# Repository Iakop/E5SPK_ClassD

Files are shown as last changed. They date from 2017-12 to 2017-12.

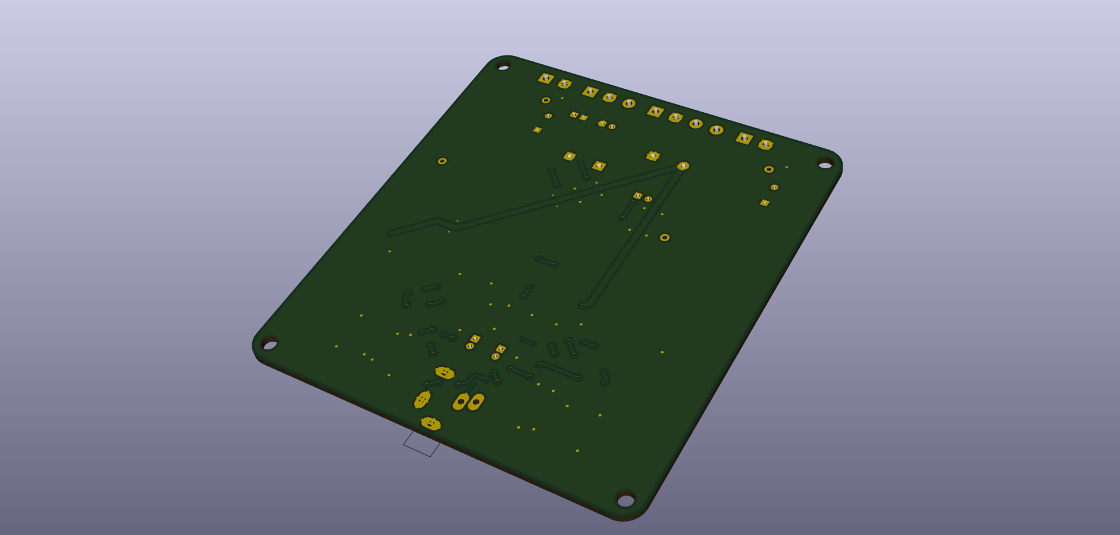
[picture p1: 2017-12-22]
documentation/Class_D_Amp_Bottom.png

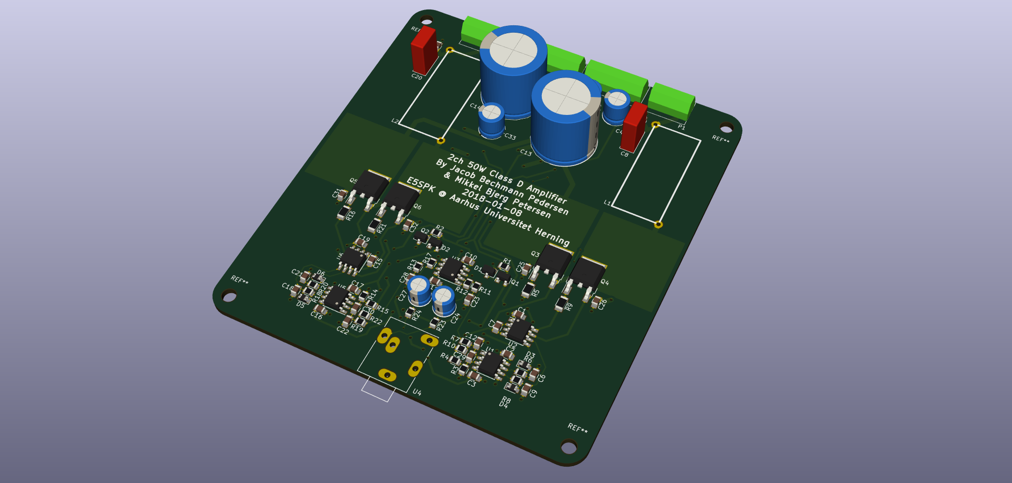
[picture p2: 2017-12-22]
documentation/Class_D_Amp_Top.png

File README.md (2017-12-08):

# E5SPK_ClassD
Class D Amplifier project for the 5th semester course, Switched Power Circuits. By Jacob Bechmann Pedersen and Mikkel Bjerg Petersen.

## Tools 
- The project calculations are alle done in MathCAD Prime
  - but might be converted to another format if needed
- The simulations are done in LTSpice
- Schematics and board layout are done in KiCad

## Key Components
- UCC27201 - 120V bootstrap Half H Driver
- LM360 - 5V High-speed comparator
- IPD180N10N3 - 43A 100V 33mΩ MOSFET DPAK
- BZX84C5V6 - 5.6V Zener Diode
- LM833 - Dual Audio OpAmp
- IES101-4 - TRS Jack connector
- ECA1HM222 - Electorlytic 2200uF Capacitor against supply pumping

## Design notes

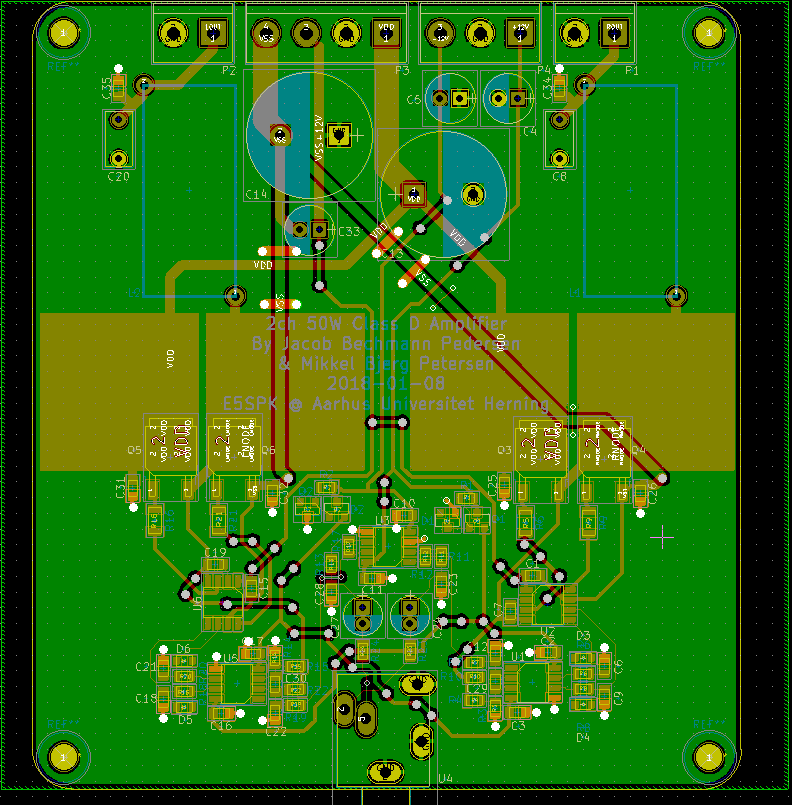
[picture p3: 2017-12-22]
documentation/Board_Layout.png

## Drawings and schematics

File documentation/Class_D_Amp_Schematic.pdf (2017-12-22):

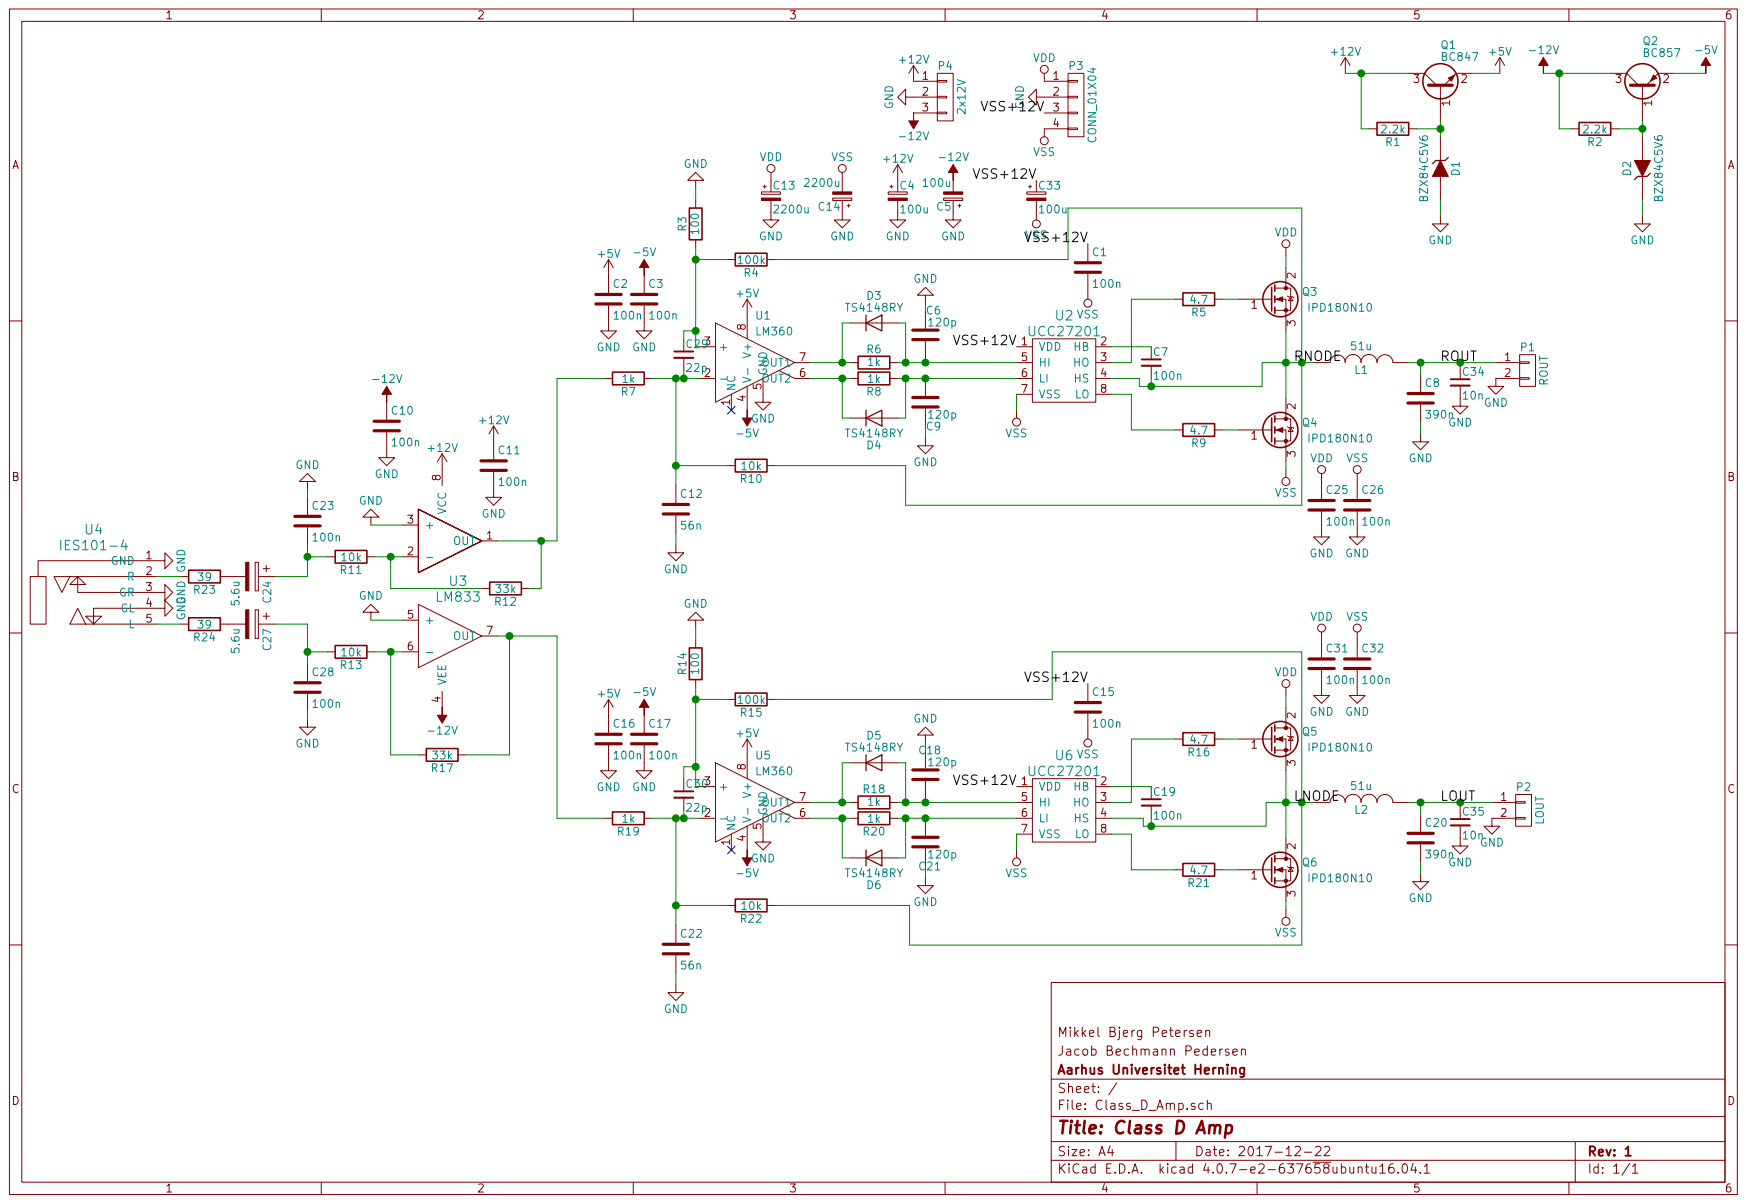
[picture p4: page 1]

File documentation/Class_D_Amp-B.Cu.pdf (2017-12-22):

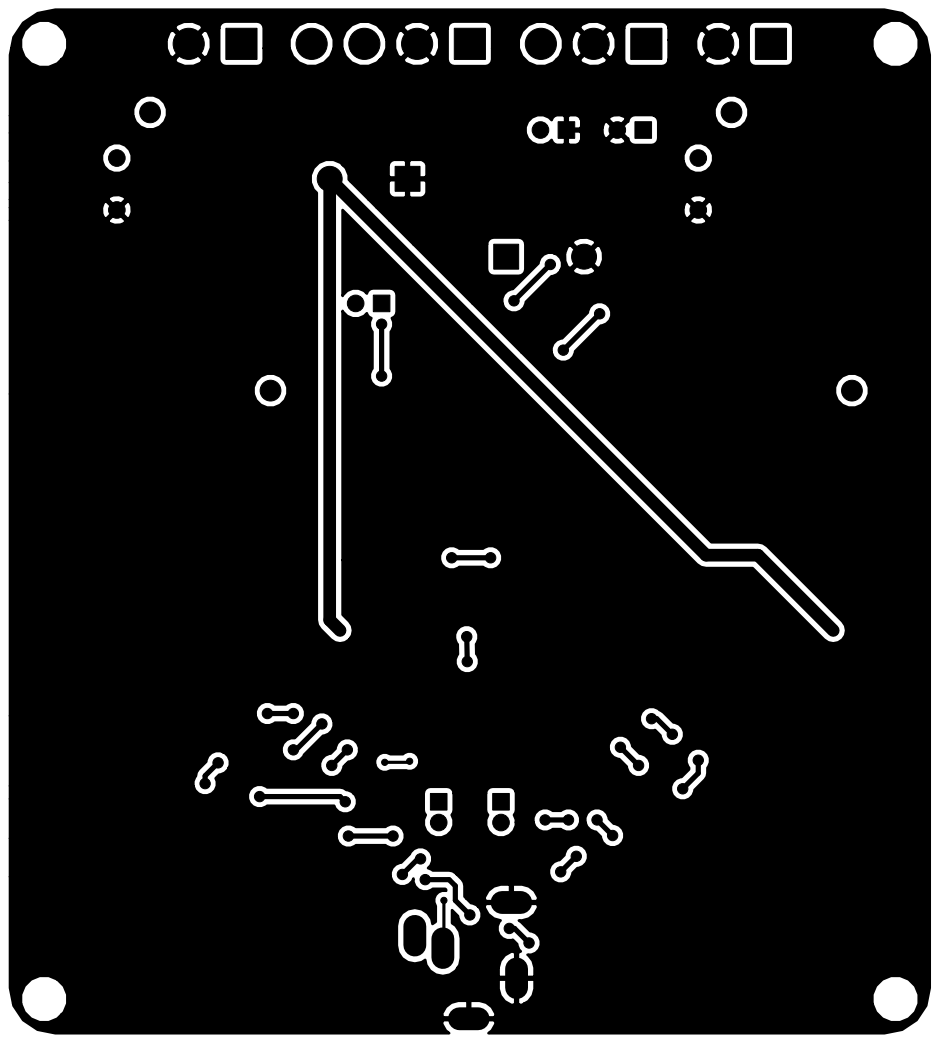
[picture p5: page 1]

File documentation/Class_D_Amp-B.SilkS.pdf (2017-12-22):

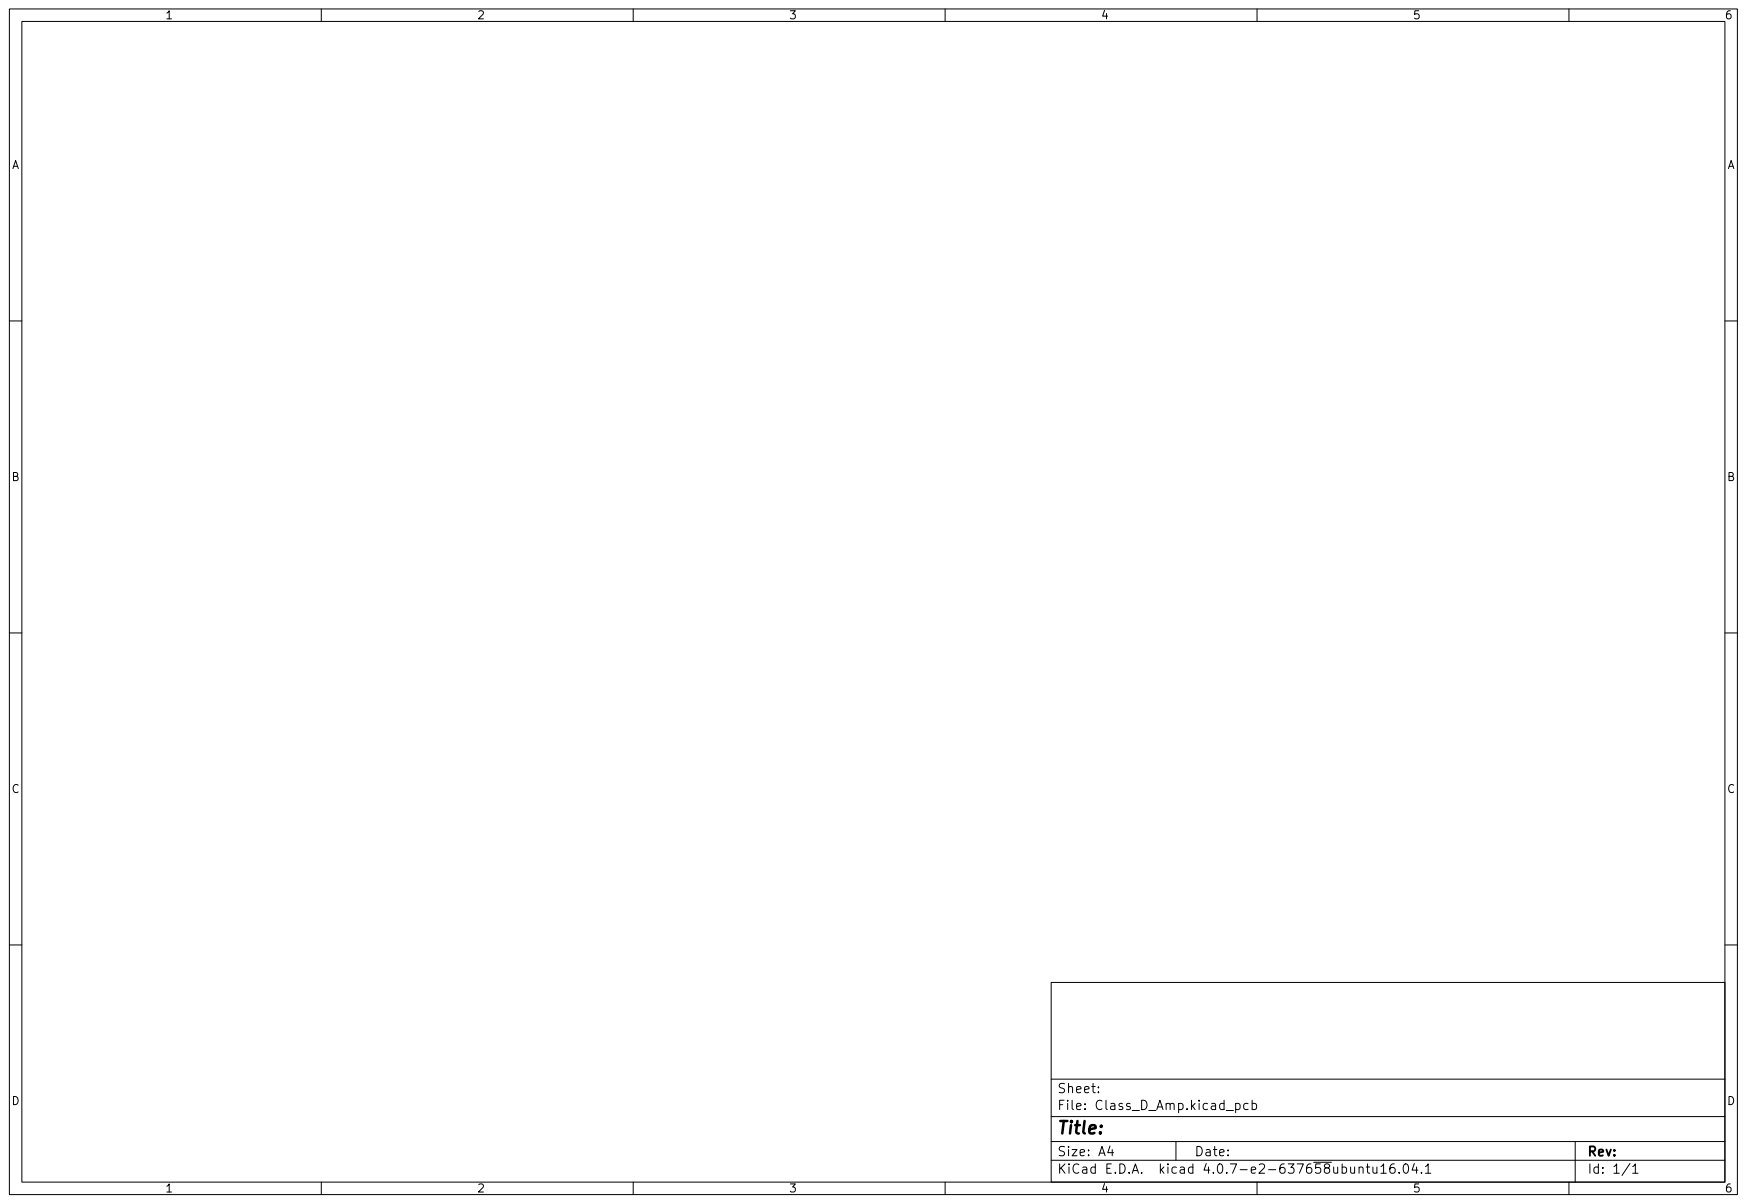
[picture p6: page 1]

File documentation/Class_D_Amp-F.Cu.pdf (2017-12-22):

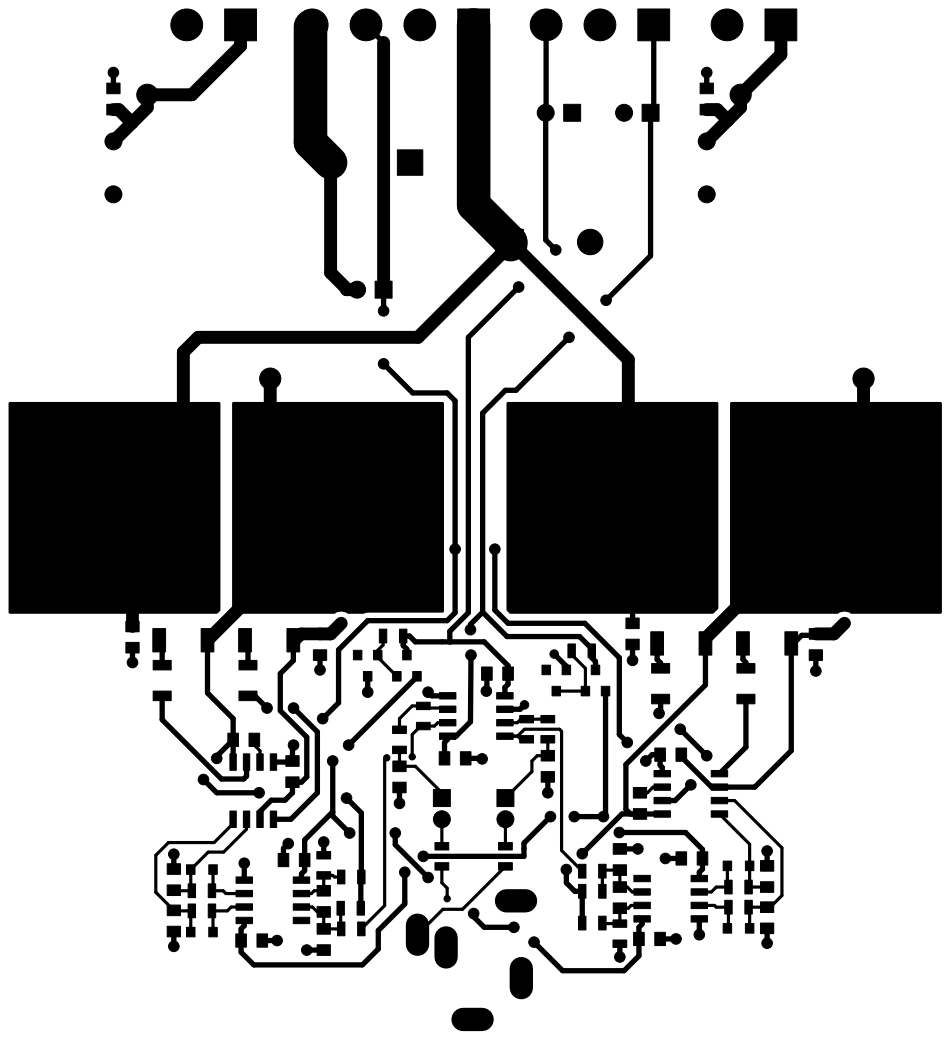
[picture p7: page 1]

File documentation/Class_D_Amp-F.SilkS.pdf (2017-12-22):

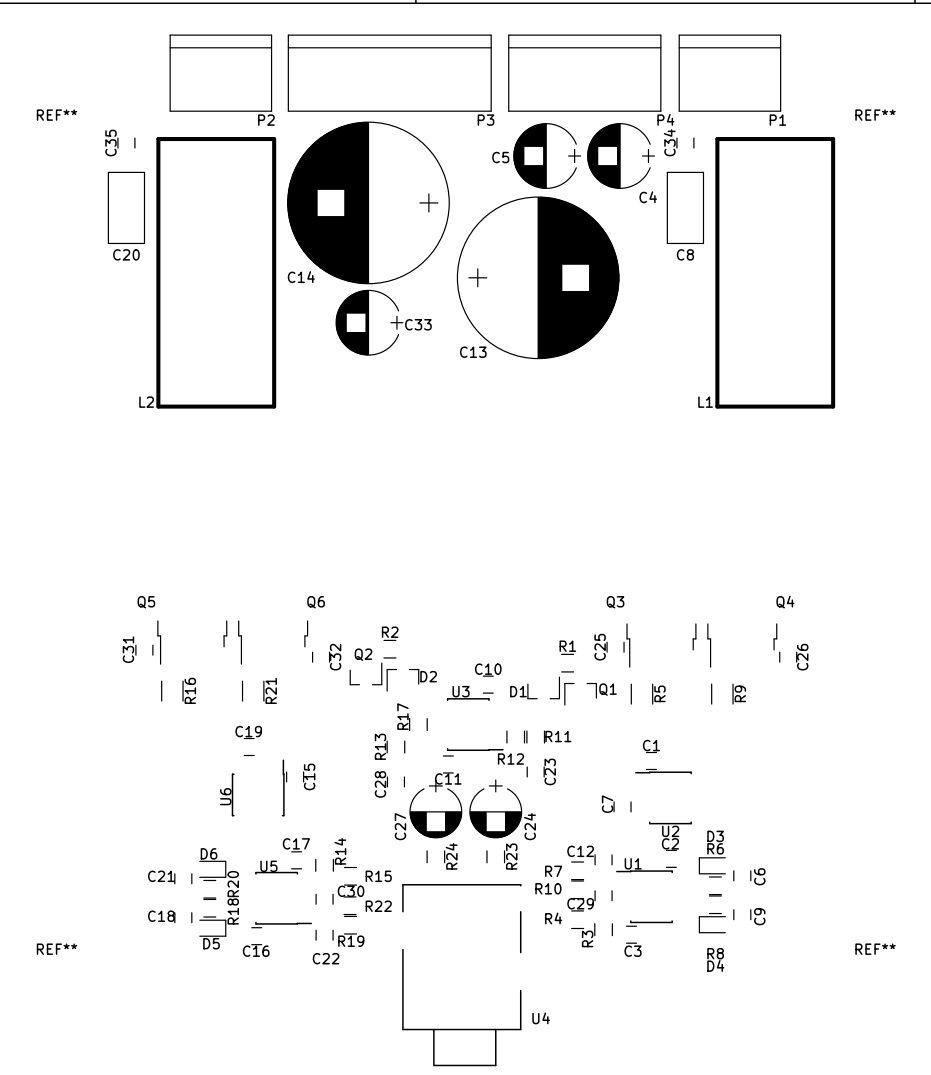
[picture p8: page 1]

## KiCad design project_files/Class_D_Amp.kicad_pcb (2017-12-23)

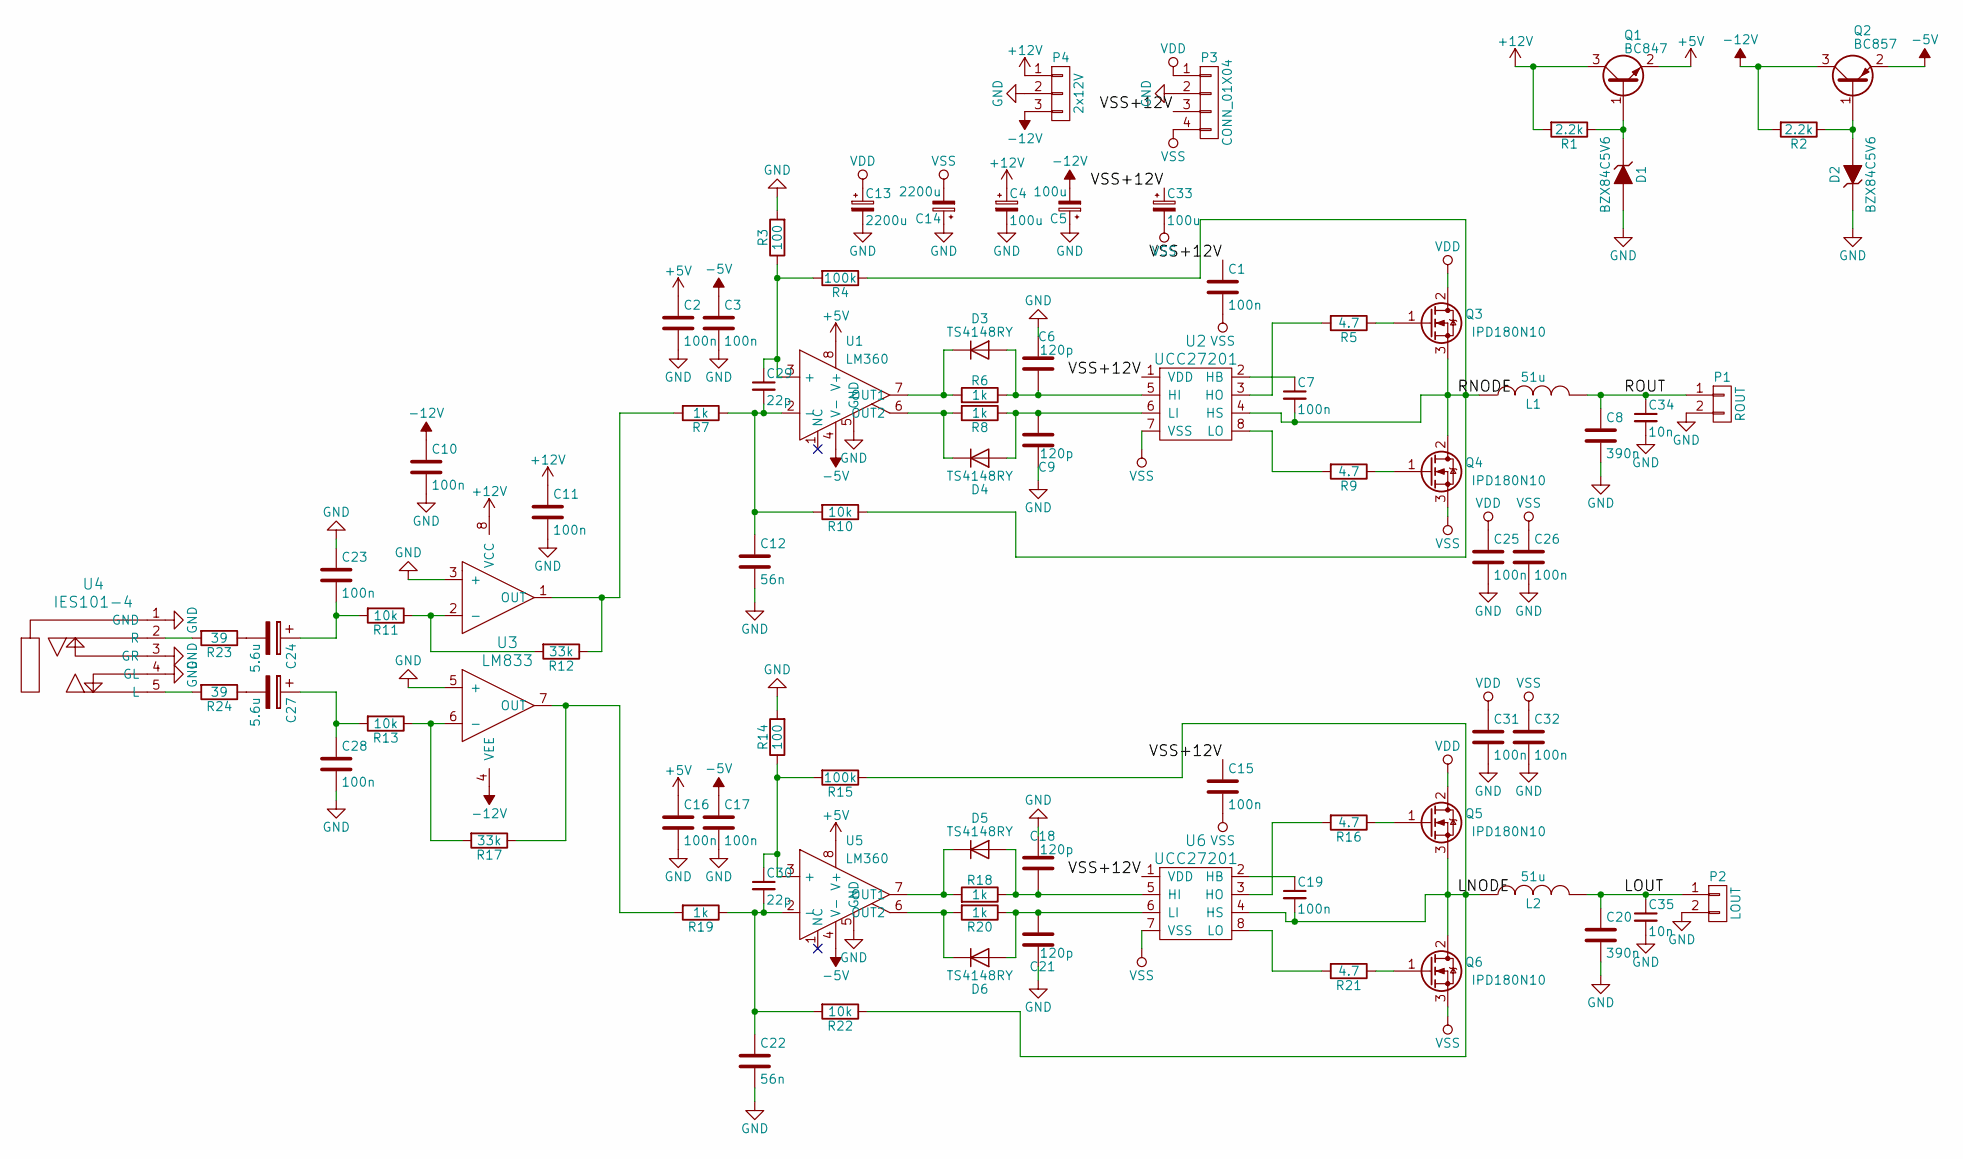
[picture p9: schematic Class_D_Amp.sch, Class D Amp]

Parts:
C1, C2, C3, C7, C10, C11, C15, C16, C17, C19, C23, C25, C26, C28, C31, C32: 100n; C_0805
C4, C5, C33: 100u; CP_Radial_D6.3mm_P2.50mm
C6, C9, C18, C21: 120p; C_0805
C8, C20: 390n; C_Rect_L7.0mm_W3.5mm_P5.00mm
C12, C22: 56n; C_0805
C13, C14: 2200u; CP_Radial_D16.0mm_P7.50mm
C24, C27: 5.6u; CP_Radial_D5.0mm_P2.00mm
C29, C30: 22p; C_0805
C34, C35: 10n; C_0805
D1, D2: BZX84C5V6; SOT-23
D3, D4, D5, D6: TS4148RY; D_0805
L1, L2: 51u; 3C20
P1: ROUT; TerminalBlock_bornier-2_P5.08mm
P2: LOUT; TerminalBlock_bornier-2_P5.08mm
P3: CONN_01X04; TerminalBlock_bornier-4_P5.08mm
P4: 2x12V; TerminalBlock_bornier-3_P5.08mm
Q1: BC847; SOT-23
Q2: BC857; SOT-23
Q3, Q4, Q5, Q6: IPD180N10; TO-252-2
R1, R2: 2.2k; R_0805
R3, R14: 100; R_0805
R4, R15: 100k; R_0805
R5, R9, R16, R21: 4.7; R_1206
R6, R7, R8, R18, R19, R20: 1k; R_0805
R10, R11, R13, R22: 10k; R_0805
R12, R17: 33k; R_0805
R23, R24: 39; R_0805
U1, U5: LM360; SOIC-8_3.9x4.9mm_Pitch1.27mm
U2, U6: UCC27201; SOIC-8_3.9x4.9mm_Pitch1.27mm
U3: LM833; SOIC-8_3.9x4.9mm_Pitch1.27mm
U4: IES101-4; Stereo_Jack_3.5mm_Switch_Ledino_KB3SPRS

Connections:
+5V: C2.1, C16.1, Q1.2 (E), U1.8 (V+), U5.8 (V+)
+12V: C4.1, C11.1, P4.1, Q1.3 (C), R1.2, U3.8 (VCC)
-5V: C3.1, C17.1, Q2.2 (E), U1.4 (V-), U5.4 (V-)
-12V: C5.2, C10.1, P4.3, Q2.3 (C), R2.2, U3.4 (VEE)
/LNODE: C19.2, L2.1, Q5.3 (S), Q6.2 (D), R15.1, R22.1, U6.4 (HS)
/LOUT: C20.1, C35.1, L2.2, P2.1
/RNODE: C7.2, L1.1, Q3.3 (S), Q4.2 (D), R4.1, R10.1, U2.4 (HS)
/ROUT: C8.1, C34.1, L1.2, P1.1
/VSS+12V: C1.1, C15.1, C33.1, P3.3, U2.1 (VDD), U6.1 (VDD)
GND: C2.2, C3.2, C4.2, C5.1, C6.2, C8.2, C9.2, C10.2, C11.2, C12.2, C13.2, C14.1, C16.2, C17.2, C18.2, C20.2, C21.2, C22.2, C23.1, C25.2, C26.2, C28.2, C31.2, C32.2, C34.2, C35.2, D1.1 (A), D2.3 (K), P1.2, P2.2, P3.2, P4.2, R3.2, R14.2, U1.5 (GND), U3.3 (+), U3.5 (+), U4.1 (GND), U4.3 (GR), U4.4 (GL), U5.5 (GND)
unnamed: C6.1, D3.2 (A), R6.1, U2.5 (HI)
unnamed: C7.1, U2.2 (HB)
unnamed: C9.1, D4.2 (A), R8.1, U2.6 (LI)
unnamed: C12.1, C29.2, R7.1, R10.2, U1.2 (-)
unnamed: C18.1, D5.2 (A), R18.1, U6.5 (HI)
unnamed: C19.1, U6.2 (HB)
unnamed: C21.1, D6.2 (A), R20.1, U6.6 (LI)
unnamed: C22.1, C30.2, R19.1, R22.2, U5.2 (-)
unnamed: C23.2, C24.1, R11.2
unnamed: C24.2, R23.1
unnamed: C27.1, C28.1, R13.2
unnamed: C27.2, R24.1
unnamed: C29.1, R3.1, R4.2, U1.3 (+)
unnamed: C30.1, R14.1, R15.2, U5.3 (+)
unnamed: D1.3 (K), Q1.1 (B), R1.1
unnamed: D2.1 (A), Q2.1 (B), R2.1
unnamed: D3.1 (K), R6.2, U1.7 (OUT1)
unnamed: D4.1 (K), R8.2, U1.6 (OUT2)
unnamed: D5.1 (K), R18.2, U5.7 (OUT1)
unnamed: D6.1 (K), R20.2, U5.6 (OUT2)
unnamed: Q3.1 (G), R5.1
unnamed: Q4.1 (G), R9.1
unnamed: Q5.1 (G), R16.1
unnamed: Q6.1 (G), R21.1
unnamed: R5.2, U2.3 (HO)
unnamed: R9.2, U2.8 (LO)
unnamed: R11.1, R12.2, U3.2 (-)
unnamed: R7.2, R12.1, U3.1 (OUT)
unnamed: R13.1, R17.2, U3.6 (-)
unnamed: R16.2, U6.3 (HO)
unnamed: R17.1, R19.2, U3.7 (OUT)
unnamed: R21.2, U6.8 (LO)
unnamed: R23.2, U4.2 (R)
unnamed: R24.2, U4.5 (L)
VDD: C13.1, C25.1, C31.1, P3.1, Q3.2 (D), Q5.2 (D)
VSS: C1.2, C14.2, C15.2, C26.1, C32.1, C33.2, P3.4, Q4.3 (S), Q6.3 (S), U2.7 (VSS), U6.7 (VSS)

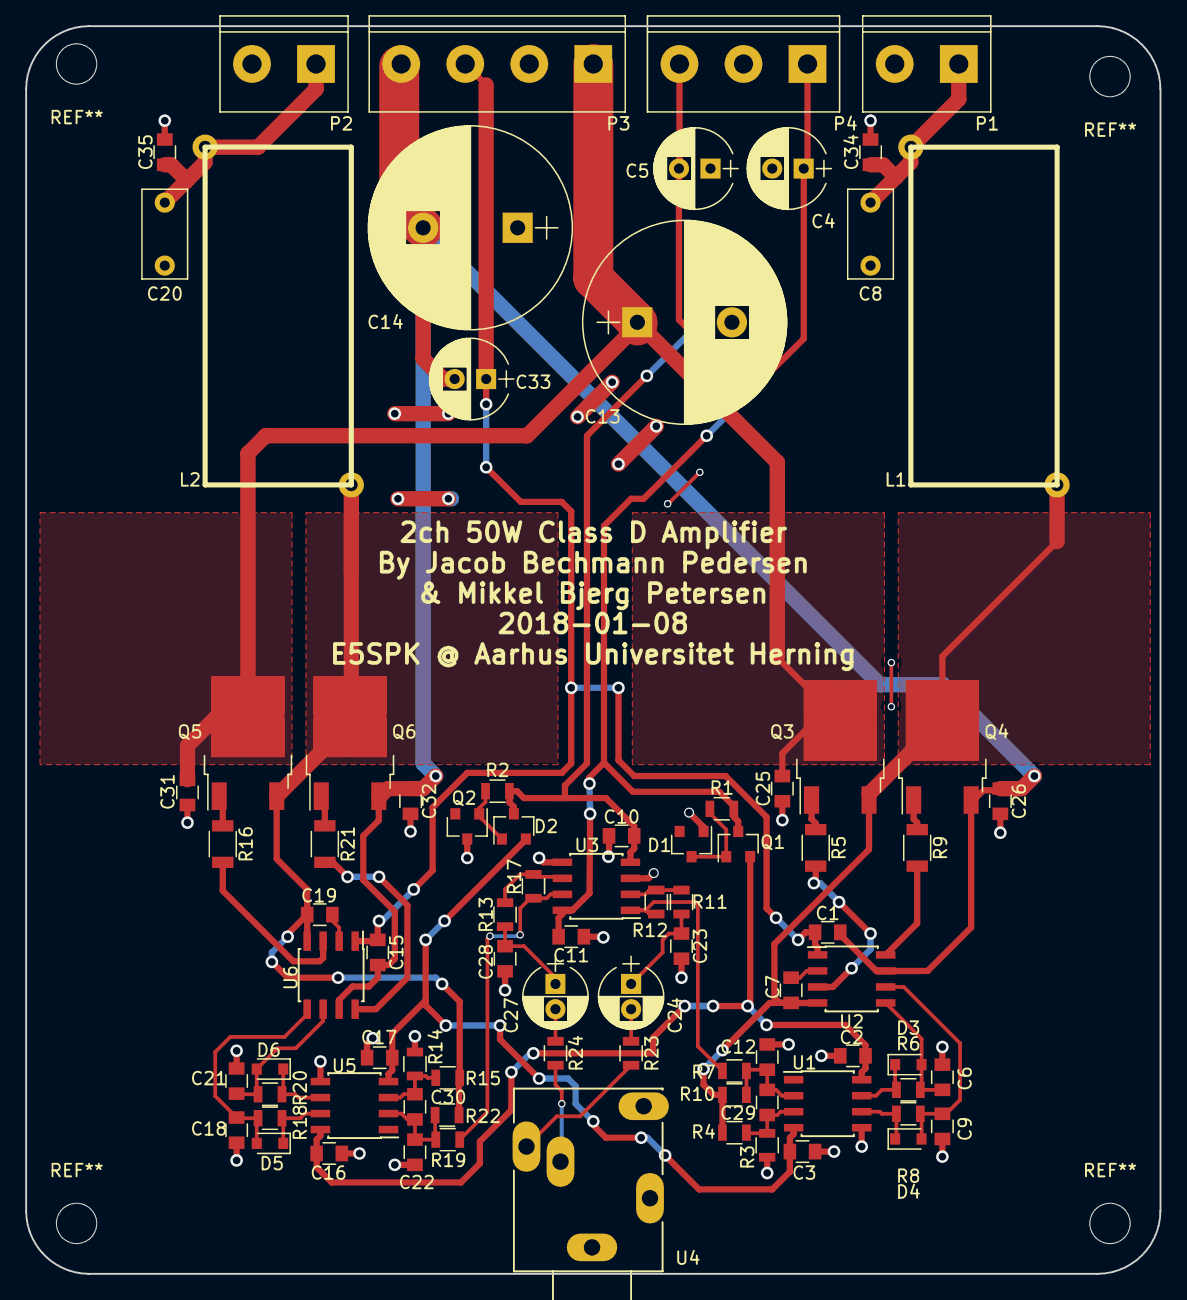
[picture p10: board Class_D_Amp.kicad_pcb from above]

Board: 2 copper layers, 90.0 x 99.0 mm, 83 parts (0 on the bottom side), 46 nets.

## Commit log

2017-12-01 Added KiCad Schematics and PCB
    [Class_D_Amp.kicad_pcb, Class_D_Amp.sch]
2017-12-01 First Schematic Version
2017-12-07 Minor updates
    [Class_D_Amp.sch]
2017-12-08 Fixed Issues in Schematic + Generated netlist
    Changed feedback to come from output nodes.
    Fixed Driver supplies
    Added global decoupling
    Hopefully fixed supply pumping
    [Class_D_Amp.kicad_pcb, Class_D_Amp.sch]
2017-12-08 Minor fix
    [Class_D_Amp.sch]
2017-12-15 Updated schematic and netlist
    [Class_D_Amp.kicad_pcb, Class_D_Amp.sch]
2017-12-15 Clustered modules together
    [Class_D_Amp.kicad_pcb, Class_D_Amp.sch]
2017-12-15 Updated PCB design
    [Class_D_Amp.kicad_pcb, Class_D_Amp.sch]
2017-12-18 Fixed Thermal pads
    [Class_D_Amp.kicad_pcb]
2017-12-22 Completed first revision of board
    [Class_D_Amp.kicad_pcb, Class_D_Amp.sch]
2017-12-22 Fixed schematic name
2017-12-23 Generated Gerbers
    [Class_D_Amp-B.Cu.gbr, Class_D_Amp-B.Mask.gbr, Class_D_Amp-B.SilkS.gbr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]
2017-12-23 fixed size
    [Class_D_Amp-B.Cu.gbr, Class_D_Amp-B.Mask.gbr, Class_D_Amp-B.SilkS.gbr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]
